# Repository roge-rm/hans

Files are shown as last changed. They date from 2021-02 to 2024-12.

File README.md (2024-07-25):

# hans
### Hans is a 5 button battery powered USB/MIDI footswitch<br>

Check Hans out on: [Youtube](https://www.youtube.com/watch?v=nbIn7SEke0U) | [Thingiverse](https://www.thingiverse.com/thing:4768840)

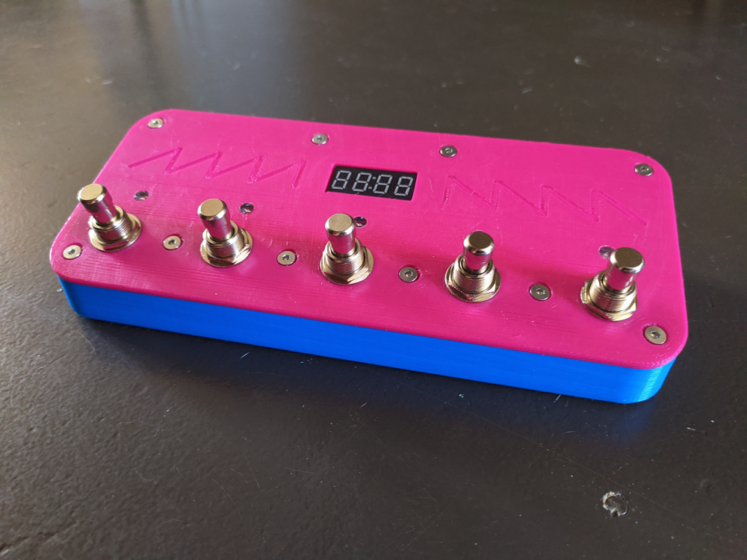
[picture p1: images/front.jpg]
<br>
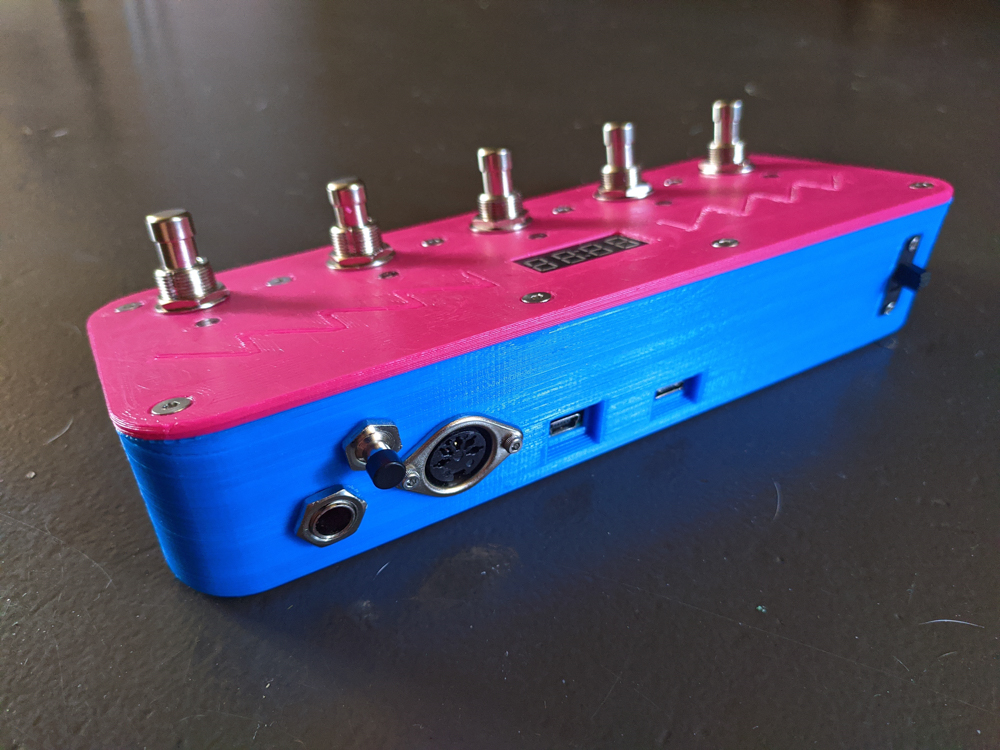
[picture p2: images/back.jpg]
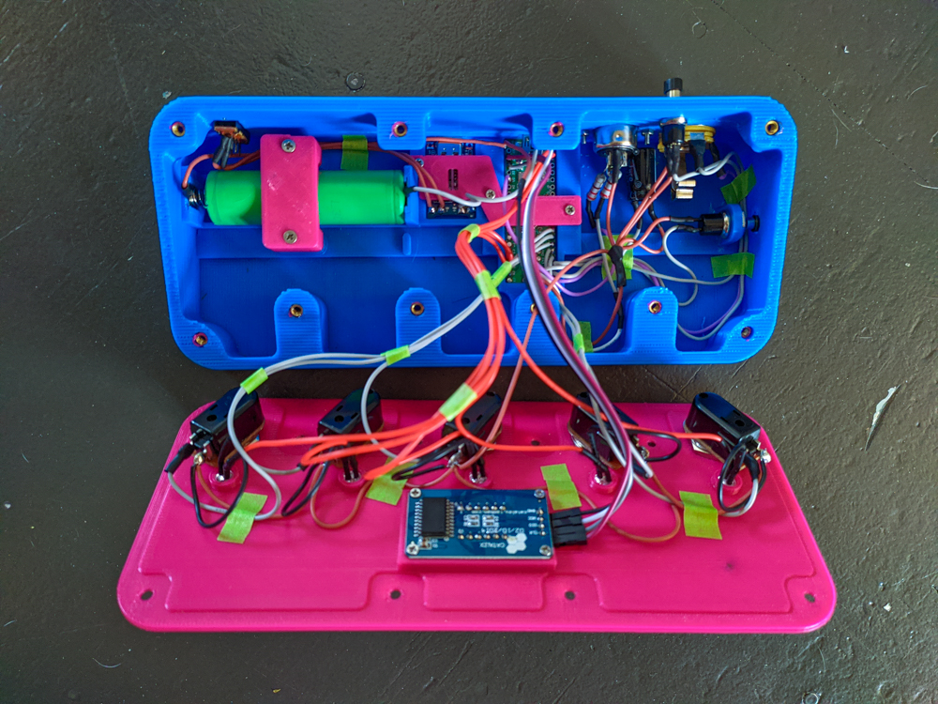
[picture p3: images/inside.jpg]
<br>

This is a continuation of a couple of previous projects of mine [[1]](https://github.com/hunked/eightbuttonMIDIfootswitch)[[2]](https://github.com/hunked/footie). 

My goal is to make a durable, 3D printed, battery powered, MIDI footswitch that outputs over USB and 5 pin MIDI. <br>
For cheap.<br>

Why did I name it Hans? No good reason at all.

### Hans has the following hardware/features:
- 5 momentary foot switches with status LEDs
- Expression pedal input (works in all button modes)
- Up to 5 virtual "banks" of buttons that can be switched between (3 enabled by default but can be changed in the edit menu)
- Full editing of all footswitch functions from the switch itself - you don't need to use your computer at all to change any settings. 
- Changes can be saved to EEPROM and will be loaded automatically on startup.
- USB-C charging with an 18650 on board for portable power
- USB (mini) and 5-pin MIDI cable connections for MIDI data
- [Teensy 2.0++](https://www.pjrc.com/store/teensypp.html) brains running at a blazing 16Mhz
- a 4 character screen

When Hans is turned on you can choose between four modes: 
- send MIDI note on/off messages (*alternative momentary mode can be activated to send note on for both press & release*)
- send MIDI control change (CC) messages
- send MIDI program change (PC) messages
- an edit mode to customize all features of the footswitch

The first three modes are self-explanatory. Both the note on/off and CC modes can be toggled between momentary and toggle operations (done by holding shift + pressing button 2), and each note can be switched between two momentary modes; one sends note on/note off on press/release and the other sends note on messages on both press and reelease.

The edit mode allows changing most of the settings on the device. You can change the midi notes sent (and the velocity sent with them), the control change numbers and values, and program change numbers. You can also edit the default mode (in case you want to start in CC or PC mode), the timeout before the default mode is selected, and various other settings like screen and LED brightness.

### How to use Hans:
- Turn Hans on.
- You will be presented with a mode selection screen. Press a button to choose a mode. <br>If no mode choice is made the default will be chosen after a timeout (5 seconds).
  * Button 1 - Note On/Off
  * Button 2 - Control Change
  * Button 3 - Program Change
  * Button 5 - Edit Mode
- If you selected modes 1 through 3:
  * Press the footswitch buttons to send the note/CC/PC message associated with that button.
  * Hold the shift button and press one of the front switches for additional functions:
    * Button 1/5 - Change button bank (-/+)
    * Button 2 - Switch between momentary/toggle modes
    * Button 3 - Return to mode select menu
    * Button 4 - Panic! Stop all playing notes
- If you selected edit mode:
  * Navigate through menus/submenus using the following buttons:
    * Button 1 - Go back to previous menu
    * Button 2 - Previous item (in menu) OR Reduce value by 1 (when editing)
    * Button 3 - Select item (in menu) or accept value (when editing)
    * Button 4 - Next item (in menu) or Increase value by 1 (when editing)
  * **Changes will not be saved to EEPROM (to be loaded on next startup) unless you select SAVE from the either the main menu or under the DATA submenu.** If you make a change you do not like you can either restart the unit, load the settings from EEPROM (under DATA submenu), or load the factory defaults (also under DATA submenu).

### Updating Hans:

Hans can be easily updated from a computer running Windows 7/8/10. 

1. Download the Teensy Loader app [from here](https://www.pjrc.com/teensy/loader_win10.html)
2. Download the [latest release](https://github.com/hunked/hans/releases) HEX file
3. Run the Teensy Loader and connect your Hans to your computer using a mini-USB cable
4. Open the hex file you downloaded in Teensy Loader and enable automatic mode in the loader
5. Press the programming button on your Hans (the one embedded in the right side) and the firmware will upload
6. Disconnect Hans when complete - you are ready!

### Replacing/Installing Battery:

You can install/remove/replace the battery in your Hans by following these steps:

1. Ensure the power to Hans is turned off, no cables are connected, etc.
2. Remove the ten hex screws on the face and set aside.
3. Carefully lift the back of the face of footswitch and flip it forward, making sure not to snag any wiring.
4. Remove the two phillips screws holding the battery clamp down.
5. Insert/remove/replace the battery as needed.
6. Reinstall the battery clamp with the two screws.
7. Carefully flip the face of the footswitch back onto the base, making sure not to snag any wiring.
8. Install the ten hex screws on the face in whatever order pleases you. I like to install from the centre outwards.

You may need a bit of gentle pressure when reinstalling the face to push any wiring down - however it should not be snagged anywhere and you should not have to force the face down onto the base. There should be enough room in the inner cavity to neatly fold any wiring into a place that does not cause any stress to the wiring or internal components.

### Pinout:<br>
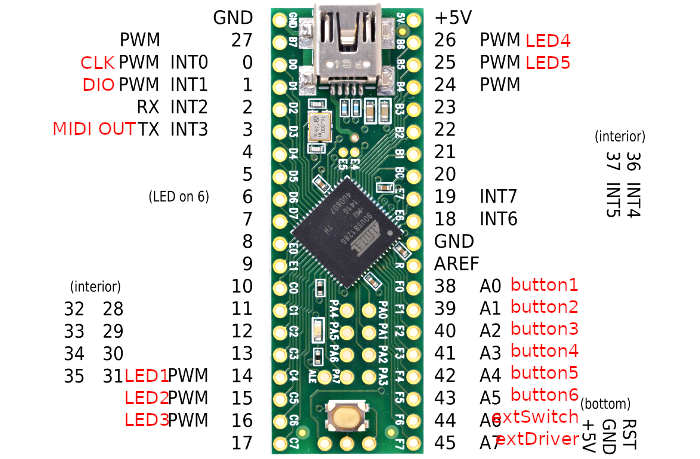
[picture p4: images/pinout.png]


### KiCad Schematic:<br>
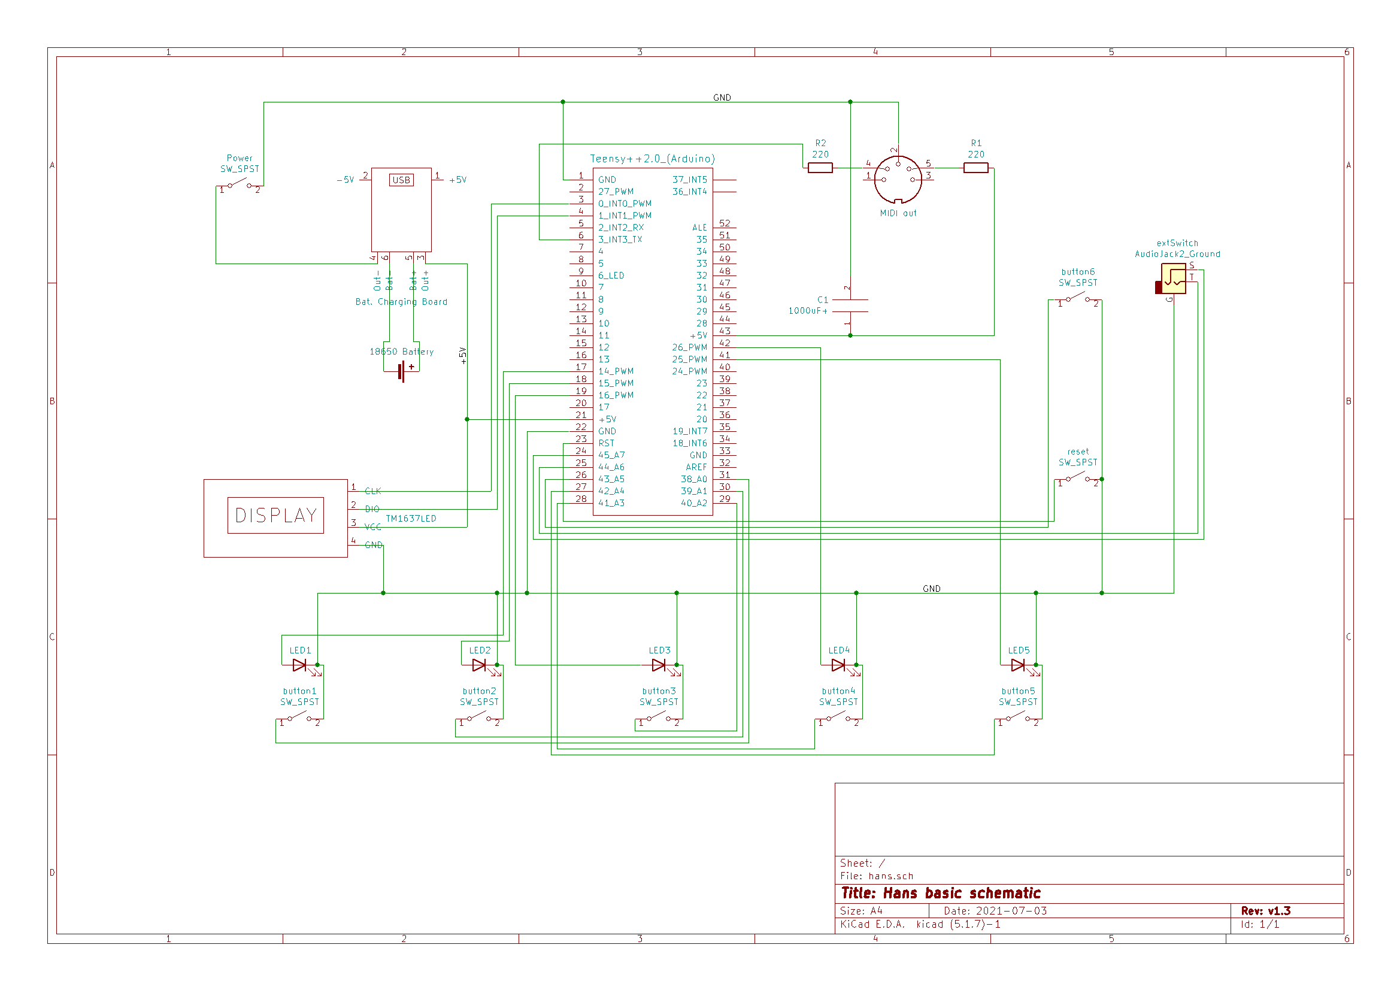
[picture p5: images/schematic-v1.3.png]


### Parts list:
| Name | Quantity |
|---|---|
| [Toggle Switch 2 Position 6 Pins](https://www.aliexpress.com/item/32800053774.html) | 1 |
| [SPST Momentary Soft Touch Push Button Stomp Foot Pedal Switch](https://www.aliexpress.com/item/32918205335.html) | 5 |
| [6.35mm Mono Female Jack With Switch Socket Panel Adapter](https://www.aliexpress.com/item/32614113278.html) | 1 |
| [5 Pin Panel Mount Female Jack DIN Adapter MIDI Connector](https://www.aliexpress.com/item/32972269819.html) | 1 |
| [7mm Momentary Push button Switch](https://www.aliexpress.com/item/32790920961.html) | 2 |
| [TM1637 4 Bits Digital LED Display Module](https://www.aliexpress.com/item/32387190376.html) | 1 |
| [Flat Top 5V 5mm Red LED Lamp w/integrated resistor](https://www.aliexpress.com/item/32904653006.html) | 5 |
| [Type-C 5V 1A 18650 Lithium Battery Charger Module](https://www.aliexpress.com/item/32670803042.html) | 1 |
| [Battery Spring and Plate Set](https://www.aliexpress.com/item/32881285245.html) | 1 |
| [Teensy 2.0++ USB AVR Development Board](https://www.pjrc.com/store/teensypp.html) or [clone](https://www.aliexpress.com/item/32975352827.html) | 1 |
| [1000uF+ 6.3V+ Capacitor](https://www.aliexpress.com/item/4000092084550.html) | 1 |
| [220 Ohm Resistor 1/4W](https://www.aliexpress.com/item/32952657927.html) | 2 |
| [M3 Thread Knurled Brass Threaded Heat Set](https://www.aliexpress.com/item/4001185849382.html) | 10 |
| [M3x10 Stainless Countersunk Hex Head Bolt](https://www.aliexpress.com/item/4000020967604.html) | 10 |
| [M2x6mm Stainless Countersunk Self-Tapping Screw](https://www.aliexpress.com/item/4001074924245.html) | 6 |
| [M2x10mm Stainless Hex Head Bolt](https://www.aliexpress.com/item/32810852732.html) | 2 |
| [M2 Stainless Nut](https://www.aliexpress.com/item/32977174437.html) | 2 |

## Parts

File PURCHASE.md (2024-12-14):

### Purchase a prebuilt Hans
I had a couple of prebuilt units for sale but they are gone.
Thanks!

### Currently for sale:
None for sale, thanks for looking!

### Sold:
**Serial:** 001<br>
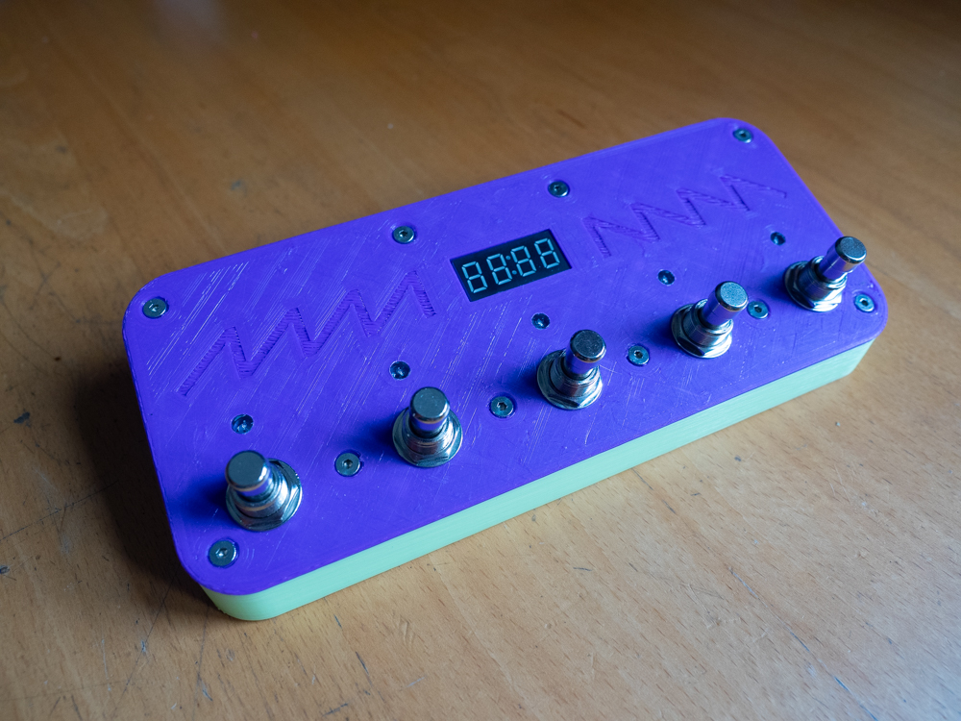
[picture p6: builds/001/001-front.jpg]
<br>
**Colours:** Light Green Base/Purple Top<br>
**Pictures:** [Rear](https://raw.githubusercontent.com/hunked/hans/main/builds/001/001-rear.jpg) [Top](https://raw.githubusercontent.com/hunked/hans/main/builds/001/001-top.jpg) [Bottom](https://raw.githubusercontent.com/hunked/hans/main/builds/001/001-bottom.jpg) [Inside](https://raw.githubusercontent.com/hunked/hans/main/builds/001/001-inside.jpg) 

**Serial:** 002<br>
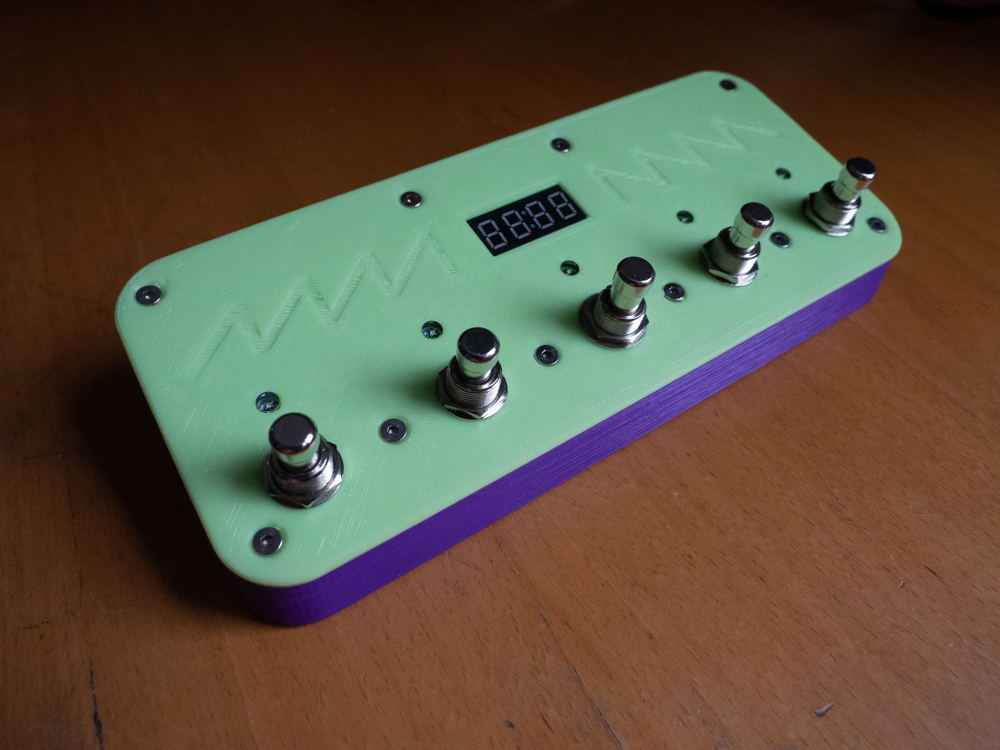
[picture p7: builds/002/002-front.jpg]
<br>
**Colours:** Purple Base/Light Green Top<br>
**Pictures:** [Rear](https://raw.githubusercontent.com/hunked/hans/main/builds/002/002-rear.jpg) [Top](https://raw.githubusercontent.com/hunked/hans/main/builds/002/002-top.jpg) [Bottom](https://raw.githubusercontent.com/hunked/hans/main/builds/002/002-bottom.jpg) [Inside](https://raw.githubusercontent.com/hunked/hans/main/builds/002/002-inside.jpg)

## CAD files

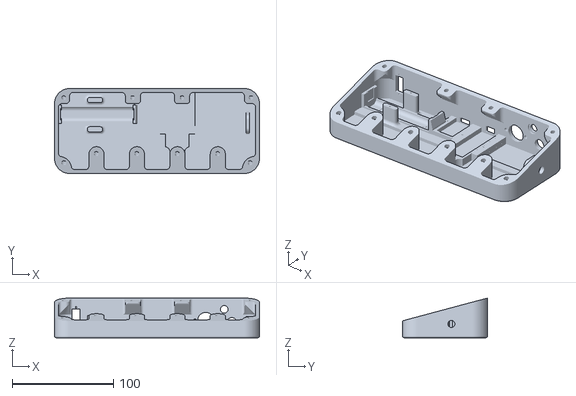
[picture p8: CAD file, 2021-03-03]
stl/v57-Main.stl
202.7 x 84.0 x 39.4

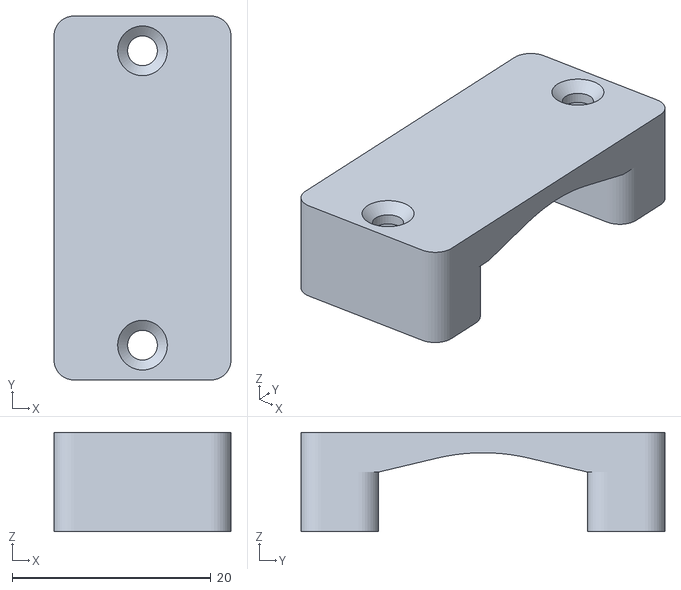
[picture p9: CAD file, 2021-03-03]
stl/v57-Battery Clamp.stl
17.8 x 36.6 x 10.0

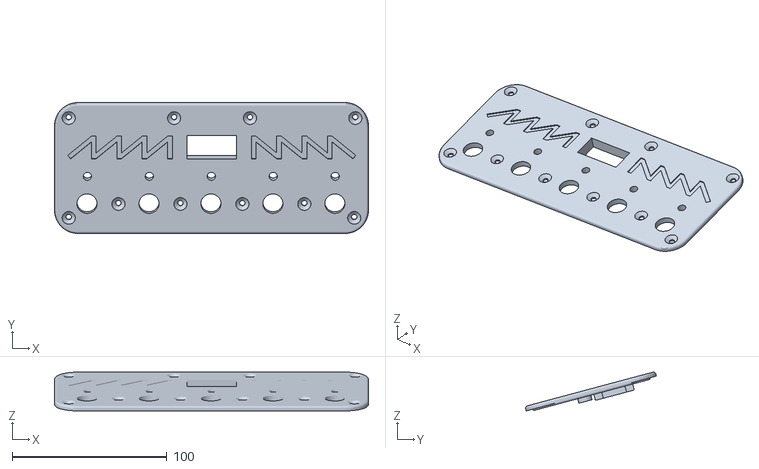
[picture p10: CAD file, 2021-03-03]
stl/v57-Top.stl
202.7 x 84.4 x 25.1

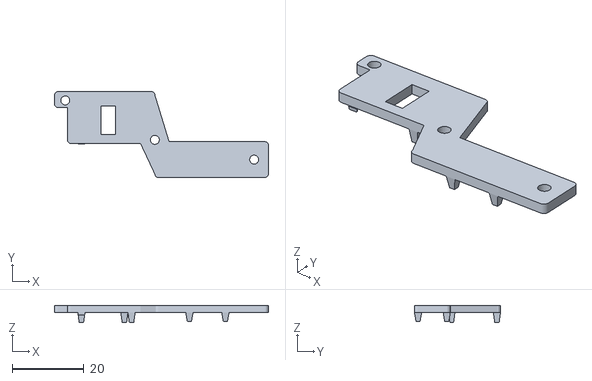
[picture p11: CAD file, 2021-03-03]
stl/v57-Board Clamp.stl
59.7 x 24.0 x 4.75

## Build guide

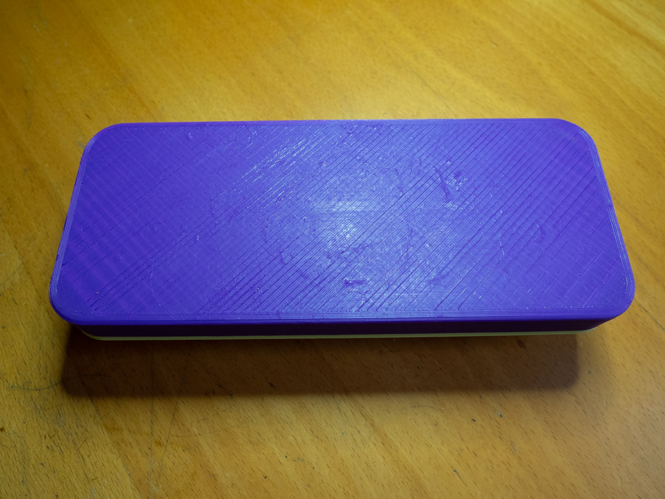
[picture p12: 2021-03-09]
builds/002/002-bottom.jpg

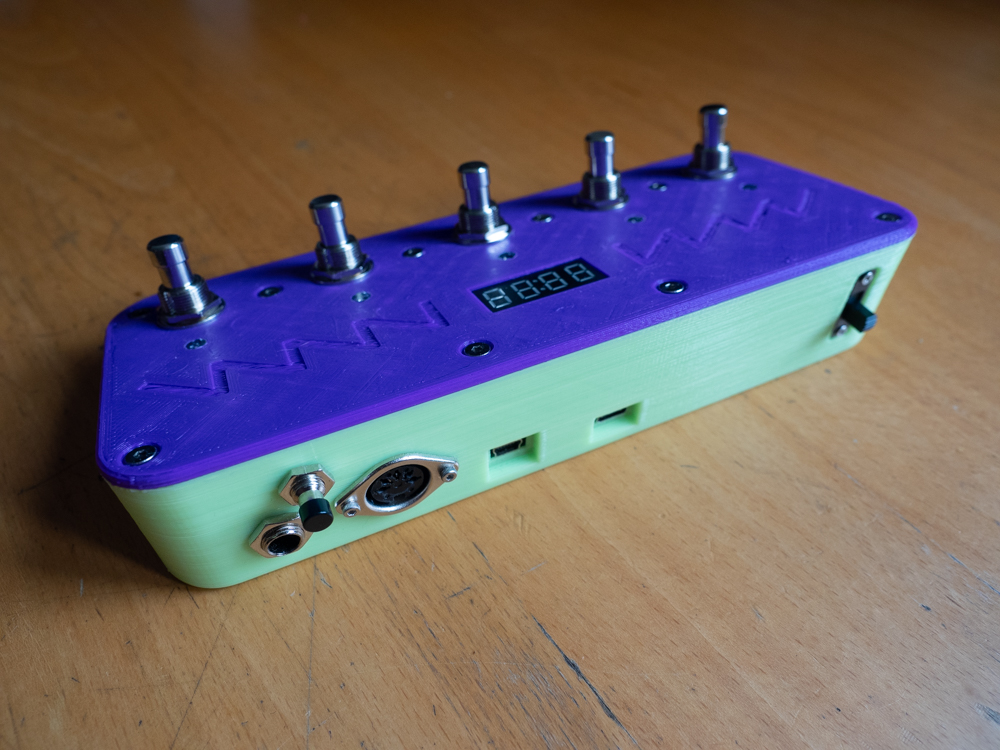
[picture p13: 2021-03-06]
builds/001/001-rear.jpg

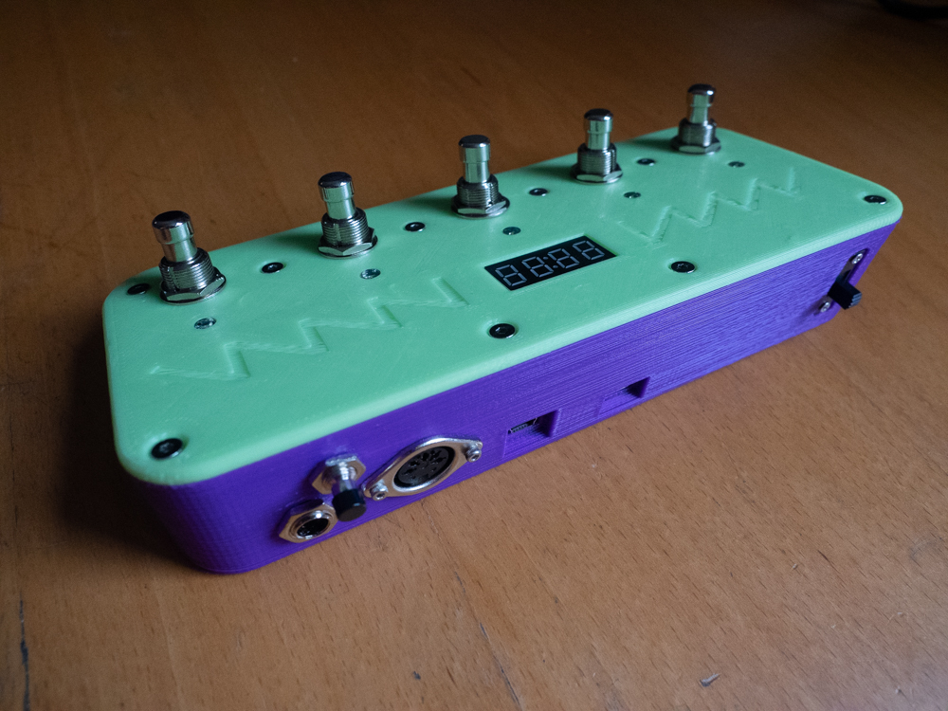
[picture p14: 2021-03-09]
builds/002/002-rear.jpg

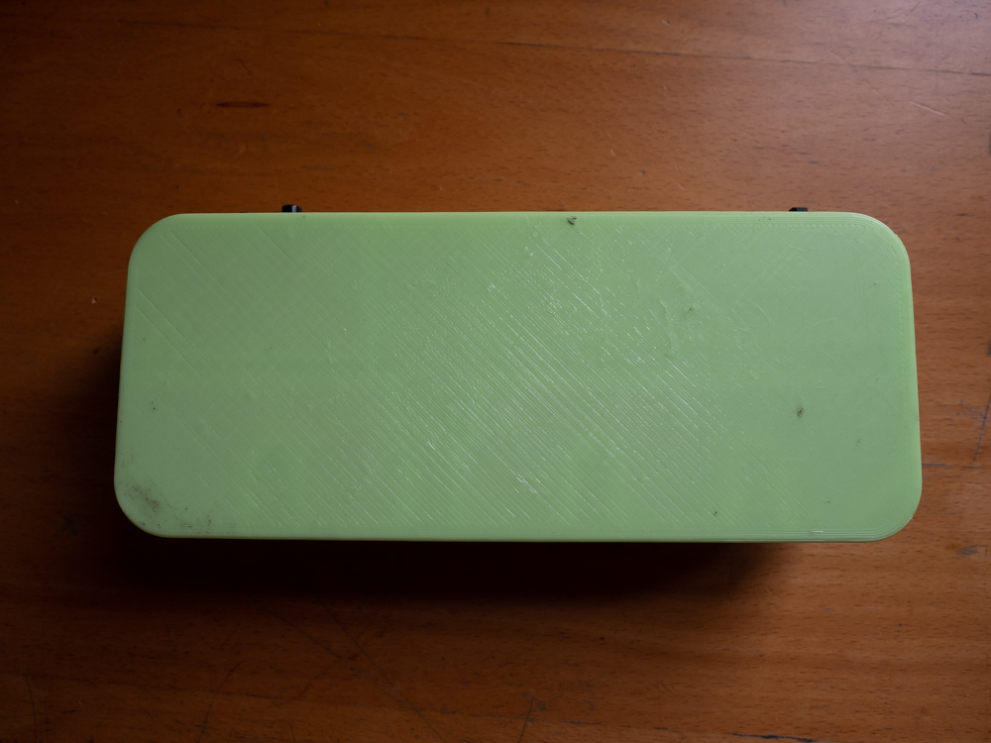
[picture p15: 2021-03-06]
builds/001/001-bottom.jpg

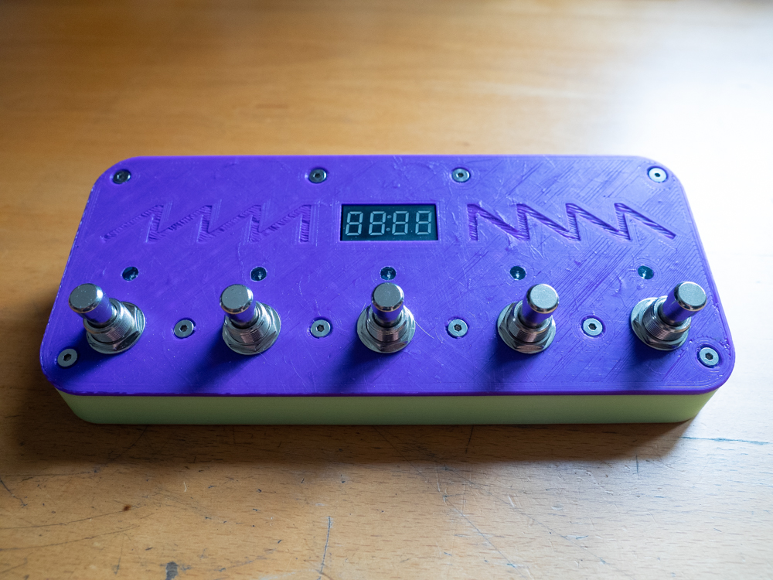
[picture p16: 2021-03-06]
builds/001/001-top.jpg

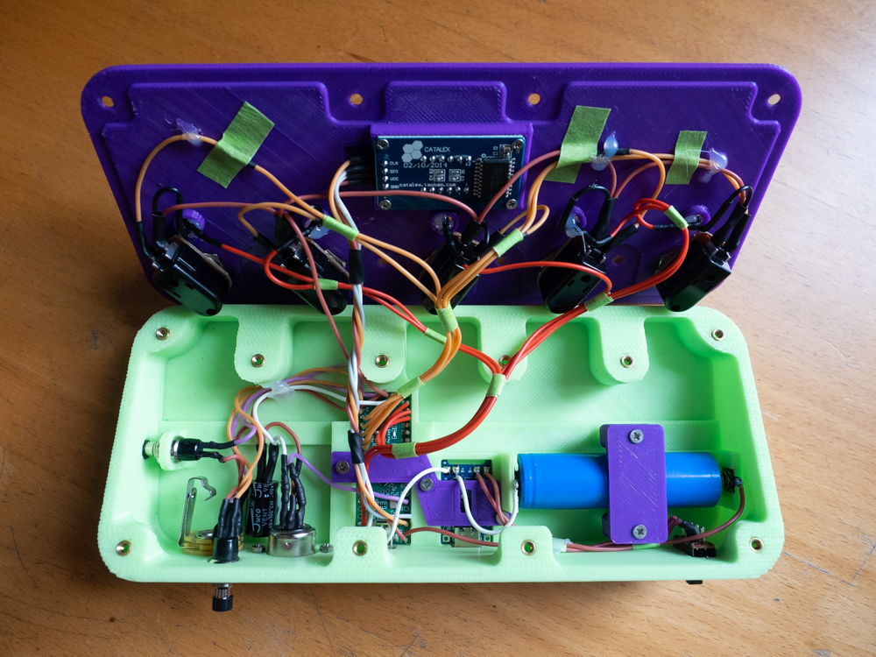
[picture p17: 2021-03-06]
builds/001/001-inside.jpg

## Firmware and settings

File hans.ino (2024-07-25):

/*
   5 buttons and an expression pedal walk in to a bar.
*/

#define buildRev "20240725"
bool intro;  // set by EEPROM - decide whether to show the name/buildrev intro text - set in eeprom

#include <Bounce2.h>
#include <MIDI.h>
#include <EEPROM.h>
#include <TM1637TinyDisplay.h>

// create MIDI instance for 5 pin MIDI output
MIDI_CREATE_INSTANCE(HardwareSerial, Serial1, MIDI);

// for buttons and external expression pedal (acts as an extra button)
const byte switchPin[6] = { 38, 39, 40, 41, 42, 43 };
const byte potPin = 44;
int potCC = 4;  // what CC the expression pedal should send
int potValue;   // store value of external pedal

// shift mode is enabled when rear button is pressed
bool shift = false;

// control whether button presses are momentary (false) or toggle (only applies to note and CC modes)
bool toggle;
bool toggleDefault;  // set by EEPROM

// LED settings
int ledBright;  // set by EEPROM - control LED brightness
const byte ledPin[5] = { 14, 15, 16, 26, 25 };
const int ledDelay = 125;  //How long to light LEDs up for visual confirmation

//Default channel for MIDI notes, CC, program change
int midiChan[3];  // set by EEPROM

// can select from up to 5 switchBanks of notes/velocities/etc - defaults to 3
int switchBank = 0;
int numBanks;  // set by EEPROM

// arrays are declared here but loaded from EEPROM/defaults in eepromREAD()
int switchNotes[5][5];       // note messages
int switchVels[5][5];        // note velocity
bool switchAltMoment[5][5];  // enable alternative momentary mode - this sends a note on message on button press and another note on message on button release
int switchCCs[5][5];         // CC numbers
int switchCCValOns[5][5];    // CC on value
int switchCCValOffs[5][5];   // CC off value
int switchPCs[5][5];         // PC numbers

bool ledStatus[5][5] = { { 0, 0, 0, 0, 0 }, { 0, 0, 0, 0, 0 }, { 0, 0, 0, 0, 0 }, { 0, 0, 0, 0, 0 }, { 0, 0, 0, 0, 0 } };

// switch states for runModes that require toggling
bool switchStates[5][5] = { { 0, 0, 0, 0, 0 }, { 0, 0, 0, 0, 0 }, { 0, 0, 0, 0, 0 }, { 0, 0, 0, 0, 0 }, { 0, 0, 0, 0, 0 } };

bool buttonStates[6] = { 0, 0, 0, 0, 0, 0 };  // track whether each button is held or not
unsigned long buttonPressTime[6];             // track how long button is pressed for
const int buttonRepeatDelay = 250;            // how long a button must be pressed for to count as a repeat (when editing)

// create Bounce objects for each button and switch.
Bounce button1 = Bounce();
Bounce button2 = Bounce();
Bounce button3 = Bounce();
Bounce button4 = Bounce();
Bounce button5 = Bounce();
Bounce button6 = Bounce();

// Track runMode (function of footswitch) as well as pick default option if no change is made before timeout. Default timeout is 6000ms.
// 0 = Startup screen (runMode select)
// 1 = MIDI Note
// 2 = MIDI CC
// 3 = Program Change
// 5 = Edit mode
int runMode = 0;
int runModeDefault = 1;  // set by EEPROM
int runmodeTime;
int runmodeDefaultTime;          // set by EEPROM - time in s to display runmode menu before selecting default
const int runmodeTimeLong = 30;  // time in s to display runmode when you return to it manually during operation
elapsedMillis timeOut;

// for settings menu navigation
int menuPos[4] = { 0, 0, 0, 0 };
int menuSelect = 0;
char menuListMain[7][5] = { "CHAN", "NOTE", "CC", "PC", "SET", "DATA", "SAVE" };
char menuListChan[3][5] = { "NOTE", "CC", "PC" };
char menuListNote[3][5] = { "NOTE", "VEL", "ALTM" };
char menuListCC[3][5] = { "CC", "V ON", "VOFF" };
char menuListSettings[9][5] = { "DRUN", "TIME", "BANK", "TOGG", "EXSW", "LEDB", "SCRB", "INFO", "IDLE" };
char menuListData[3][5] = { "LOAD", "SAVE", "DEF" };
char idleText[6][5] = { "hans", " is ", " me", "hans", " is ", " on" };

const int wipeTime = 1000;  // max time in ms to display anything on the screen
int idleTimeOut;            // set by EEPROM - time in seconds to wait before showing a keepalive notification
int idleCounter = 0;        // used to run through idle messages in order
elapsedMillis screenWipe;
elapsedMillis idleTime;

// initialize display
const int clkPin = 0;
const int dioPin = 1;
int screenBright;       // set by EEPROM - control how bright the screen is from 0-7
int scrollDelay = 100;  // speed at which text scrolls on the screen
TM1637TinyDisplay display(clkPin, dioPin);

void setup() {
  // button setup
  button1.attach(switchPin[0], INPUT_PULLUP);
  button2.attach(switchPin[1], INPUT_PULLUP);
  button3.attach(switchPin[2], INPUT_PULLUP);
  button4.attach(switchPin[3], INPUT_PULLUP);
  button5.attach(switchPin[4], INPUT_PULLUP);
  button6.attach(switchPin[5], INPUT_PULLUP);

  // button debounce interval in ms
  button1.interval(5);
  button2.interval(5);
  button3.interval(5);
  button4.interval(5);
  button5.interval(5);
  button6.interval(5);

  eepromLoad();                      // load values from EEPROM - or from default set it nothing saved to EEPROMN
  runmodeTime = runmodeDefaultTime;  // set initial runmode timeout to default timeout
  toggle = toggleDefault;

  // display setup and greeting
  display.setBrightness(screenBright);
  display.setScrolldelay(scrollDelay);
  if (intro) {
    display.showString("hans");
    delay(750);
    display.showString(buildRev);
    delay(250);
  }
  display.clear();

  // initialize MIDI
  MIDI.begin();

  // configure switch pins as for input mode with pullup resistors
  pinMode(switchPin[0], INPUT_PULLUP);
  pinMode(switchPin[1], INPUT_PULLUP);
  pinMode(switchPin[2], INPUT_PULLUP);
  pinMode(switchPin[3], INPUT_PULLUP);
  pinMode(switchPin[4], INPUT_PULLUP);
  pinMode(switchPin[5], INPUT_PULLUP);

  // initialize built-in LED as an output.
  pinMode(ledPin[0], OUTPUT);
  pinMode(ledPin[1], OUTPUT);
  pinMode(ledPin[2], OUTPUT);
  pinMode(ledPin[3], OUTPUT);
  pinMode(ledPin[4], OUTPUT);

  updateButtons();  // pull initial button status to prevent phantom MIDI messages from being sent once the loop starts

  display.clear();
  timeOut = 0;

  potValue = 0;
}

void loop() {
  updatePot();      // update expression pedal
  updateButtons();  // poll for button presses.

  switch (runMode) {
    case 0:
      runModeSelectMode();
      idleTime = 0;
      break;
    case 1:
      runModeNote();
      break;
    case 2:
      runModeCC();
      break;
    case 3:
      runModePC();
      break;
    case 5:
      runModeSettings();
      idleTime = 0;
      break;
  }

  while (usbMIDI.read())  // ignore incoming MIDI
  {
  }

  if (button6.changed()) {
    if (button6.rose()) {
      shift = false;
    } else if (button6.fell()) {
      shift = true;
      display.showString("Shft");
      screenWipe = 0;
    }
  }

  // wipe the screen every wipeTime ms
  if (screenWipe >= wipeTime) {
    display.clear();
    screenWipe = 0;
  }

  // show a lil somethin on the screen every idleTimeOut
  // this is because I always forget to turn Hans off
  if (idleTimeOut > 0) {
    if (idleTime >= (idleTimeOut * 1000)) {
      display.showString(idleText[idleCounter]);
      if (idleCounter < 6) idleCounter++;
      else idleCounter = 0;
      idleTime = 0;
      screenWipe = 0;
    }
  }

  updateLEDs();  // update LED status
}

void updatePot() {
  int newpotValue;
  newpotValue = (analogRead(potPin) / 8);
  if (newpotValue < 3) newpotValue = 0;
  if (newpotValue > 125) newpotValue = 127;

  if (newpotValue != potValue) {
    usbMIDI.sendControlChange(potCC, newpotValue, midiChan[2]);
    MIDI.sendControlChange(potCC, newpotValue, midiChan[2]);
    //Serial.print("external input is: ");
    //Serial.println(newpotValue);
    display.showNumber(newpotValue);
    potValue = newpotValue;
  }
}

void updateButtons() {
  if (button1.update()) {
    buttonStates[0] = !button1.read();
    idleTime = 0;
    idleCounter = 0;
  }
  if (button2.update()) {
    buttonStates[1] = !button2.read();
    idleTime = 0;
    idleCounter = 0;
  }
  if (button3.update()) {
    buttonStates[2] = !button3.read();
    idleTime = 0;
    idleCounter = 0;
  }
  if (button4.update()) {
    buttonStates[3] = !button4.read();
    idleTime = 0;
    idleCounter = 0;
  }
  if (button5.update()) {
    buttonStates[4] = !button5.read();
    idleTime = 0;
    idleCounter = 0;
  }
  if (button6.update()) {
    buttonStates[5] = !button6.read();
    idleTime = 0;
    idleCounter = 0;
  }
}

void runModeSelectMode() {  // give choice between running modes, choose default mode after timeout if no option selected
  display.showString("Mode");

  ledStatus[switchBank][0] = 1;
  ledStatus[switchBank][1] = 1;
  ledStatus[switchBank][2] = 1;
  ledStatus[switchBank][4] = 1;

  if (button1.rose()) {
    resetLEDs();
    updateLEDs();
    runMode = 1;
    displayText(runMode - 1, 3);
  } else if (button2.rose()) {
    resetLEDs();
    updateLEDs();
    runMode = 2;
    displayText(runMode - 1, 3);
  } else if (button3.rose()) {
    resetLEDs();
    updateLEDs();
    runMode = 3;
    displayText(runMode - 1, 3);
  } else if (button5.rose()) {
    resetLEDs();
    updateLEDs();
    runMode = 5;
    displayText(runMode - 1, 3);
  }
  screenWipe = 0;

  if (timeOut >= (runmodeTime * 1000)) {
    resetLEDs();
    updateLEDs();
    runMode = runModeDefault;
    displayText(runMode - 1, 3);
    timeOut = 0;
  }
}

void runModeNote() {
  if (button1.changed() || button2.changed() || button3.changed() || button4.changed() || button5.changed()) {
    if (!shift) {     // shift mode disabled
      if (!toggle) {  // toggle mode disabled (aka momentary mode)
        if (button1.fell()) {
          display.showNumber(switchNotes[switchBank][0]);
          ledStatus[switchBank][0] = 1;
          usbMIDI.sendNoteOn(switchNotes[switchBank][0], switchVels[switchBank][0], midiChan[0]);
          MIDI.sendNoteOn(switchNotes[switchBank][0], switchVels[switchBank][0], midiChan[0]);
        } else if (button1.rose()) {
          display.showNumber(switchNotes[switchBank][0]);
          if (!switchAltMoment[switchBank][0]) {  // normal operation - alt momentary mode disabled
            usbMIDI.sendNoteOff(switchNotes[switchBank][0], 0, midiChan[0]);
            MIDI.sendNoteOff(switchNotes[switchBank][0], 0, midiChan[0]);
          } else if (switchAltMoment[switchBank][0]) {  // alt momentary mode enabled
            usbMIDI.sendNoteOn(switchNotes[switchBank][0], switchVels[switchBank][0], midiChan[0]);
            MIDI.sendNoteOn(switchNotes[switchBank][0], switchVels[switchBank][0], midiChan[0]);
          }
          ledStatus[switchBank][0] = 0;
        }

        if (button2.fell()) {
          display.showNumber(switchNotes[switchBank][1]);
          ledStatus[switchBank][1] = 1;
          usbMIDI.sendNoteOn(switchNotes[switchBank][1], switchVels[switchBank][1], midiChan[0]);
          MIDI.sendNoteOn(switchNotes[switchBank][1], switchVels[switchBank][1], midiChan[0]);
        } else if (button2.rose()) {
          display.showNumber(switchNotes[switchBank][1]);
          if (!switchAltMoment[switchBank][1]) {
            usbMIDI.sendNoteOff(switchNotes[switchBank][1], 0, midiChan[0]);
            MIDI.sendNoteOff(switchNotes[switchBank][1], 0, midiChan[0]);
          } else if (switchAltMoment[switchBank][1]) {
            usbMIDI.sendNoteOn(switchNotes[switchBank][1], switchVels[switchBank][1], midiChan[0]);
            MIDI.sendNoteOn(switchNotes[switchBank][1], switchVels[switchBank][1], midiChan[0]);
          }
          ledStatus[switchBank][1] = 0;
        }

        if (button3.fell()) {
          display.showNumber(switchNotes[switchBank][2]);
          ledStatus[switchBank][2] = 1;
          usbMIDI.sendNoteOn(switchNotes[switchBank][2], switchVels[switchBank][2], midiChan[0]);
          MIDI.sendNoteOn(switchNotes[switchBank][2], switchVels[switchBank][2], midiChan[0]);
        } else if (button3.rose()) {
          display.showNumber(switchNotes[switchBank][2]);
          if (!switchAltMoment[switchBank][2]) {
            usbMIDI.sendNoteOff(switchNotes[switchBank][2], 0, midiChan[0]);
            MIDI.sendNoteOff(switchNotes[switchBank][2], 0, midiChan[0]);
          } else if (switchAltMoment[switchBank][2]) {
            usbMIDI.sendNoteOn(switchNotes[switchBank][2], switchVels[switchBank][2], midiChan[0]);
            MIDI.sendNoteOn(switchNotes[switchBank][2], switchVels[switchBank][2], midiChan[0]);
          }
          ledStatus[switchBank][2] = 0;
        }

        if (button4.fell()) {
          display.showNumber(switchNotes[switchBank][3]);
          ledStatus[switchBank][3] = 1;
          usbMIDI.sendNoteOn(switchNotes[switchBank][3], switchVels[switchBank][3], midiChan[0]);
          MIDI.sendNoteOn(switchNotes[switchBank][3], switchVels[switchBank][3], midiChan[0]);
        } else if (button4.rose()) {
          display.showNumber(switchNotes[switchBank][3]);
          if (!switchAltMoment[switchBank][3]) {
            usbMIDI.sendNoteOff(switchNotes[switchBank][3], 0, midiChan[0]);
            MIDI.sendNoteOff(switchNotes[switchBank][3], 0, midiChan[0]);
          } else if (switchAltMoment[switchBank][3]) {
            usbMIDI.sendNoteOn(switchNotes[switchBank][3], switchVels[switchBank][3], midiChan[0]);
            MIDI.sendNoteOn(switchNotes[switchBank][3], switchVels[switchBank][3], midiChan[0]);
          }
          ledStatus[switchBank][3] = 0;
        }

        if (button5.fell()) {
          display.showNumber(switchNotes[switchBank][4]);
          ledStatus[switchBank][4] = 1;
          usbMIDI.sendNoteOn(switchNotes[switchBank][4], switchVels[switchBank][4], midiChan[0]);
          MIDI.sendNoteOn(switchNotes[switchBank][4], switchVels[switchBank][4], midiChan[0]);
        } else if (button5.rose()) {
          display.showNumber(switchNotes[switchBank][4]);
          if (!switchAltMoment[switchBank][4]) {
            usbMIDI.sendNoteOff(switchNotes[switchBank][4], 0, midiChan[0]);
            MIDI.sendNoteOff(switchNotes[switchBank][4], 0, midiChan[0]);
          } else if (switchAltMoment[switchBank][4]) {
            usbMIDI.sendNoteOn(switchNotes[switchBank][4], switchVels[switchBank][4], midiChan[0]);
            MIDI.sendNoteOn(switchNotes[switchBank][4], switchVels[switchBank][4], midiChan[0]);
          }
          ledStatus[switchBank][4] = 0;
        }
      } else if (toggle) {
        if (button1.fell()) {
          display.showNumber(switchNotes[switchBank][0]);
          if (switchStates[switchBank][0] == 0) {
            switchStates[switchBank][0] = 1;
            usbMIDI.sendNoteOn(switchNotes[switchBank][0], switchVels[switchBank][0], midiChan[0]);
            MIDI.sendNoteOn(switchNotes[switchBank][0], switchVels[switchBank][0], midiChan[0]);
            ledStatus[switchBank][0] = 1;
          } else {
            switchStates[switchBank][0] = 0;
            usbMIDI.sendNoteOff(switchNotes[switchBank][0], 0, midiChan[0]);
            MIDI.sendNoteOff(switchNotes[switchBank][0], 0, midiChan[0]);
            ledStatus[switchBank][0] = 0;
          }
        }

        if (button2.fell()) {
          display.showNumber(switchNotes[switchBank][1]);
          if (switchStates[switchBank][1] == 0) {
            switchStates[switchBank][1] = 1;
            usbMIDI.sendNoteOn(switchNotes[switchBank][1], switchVels[switchBank][1], midiChan[0]);
            MIDI.sendNoteOn(switchNotes[switchBank][1], switchVels[switchBank][1], midiChan[0]);
            ledStatus[switchBank][1] = 1;
          } else {
            switchStates[switchBank][1] = 0;
            usbMIDI.sendNoteOff(switchNotes[switchBank][1], 0, midiChan[0]);
            MIDI.sendNoteOff(switchNotes[switchBank][1], 0, midiChan[0]);
            ledStatus[switchBank][1] = 0;
          }
        }

        if (button3.fell()) {
          display.showNumber(switchNotes[switchBank][2]);
          if (switchStates[switchBank][2] == 0) {
            switchStates[switchBank][2] = 1;
            usbMIDI.sendNoteOn(switchNotes[switchBank][2], switchVels[switchBank][2], midiChan[0]);
            MIDI.sendNoteOn(switchNotes[switchBank][2], switchVels[switchBank][2], midiChan[0]);
            ledStatus[switchBank][2] = 1;
          } else {
            switchStates[switchBank][2] = 0;
            usbMIDI.sendNoteOff(switchNotes[switchBank][2], 0, midiChan[0]);
            MIDI.sendNoteOff(switchNotes[switchBank][2], 0, midiChan[0]);
            ledStatus[switchBank][2] = 0;
          }
        }

        if (button4.fell()) {
          display.showNumber(switchNotes[switchBank][3]);
          if (switchStates[switchBank][3] == 0) {
            switchStates[switchBank][3] = 1;
            usbMIDI.sendNoteOn(switchNotes[switchBank][3], switchVels[switchBank][3], midiChan[0]);
            MIDI.sendNoteOn(switchNotes[switchBank][3], switchVels[switchBank][3], midiChan[0]);
            ledStatus[switchBank][3] = 1;
          } else {
            switchStates[switchBank][3] = 0;
            usbMIDI.sendNoteOff(switchNotes[switchBank][3], 0, midiChan[0]);
            MIDI.sendNoteOff(switchNotes[switchBank][3], 0, midiChan[0]);
            ledStatus[switchBank][3] = 0;
          }
        }

        if (button5.fell()) {
          display.showNumber(switchNotes[switchBank][4]);
          if (switchStates[switchBank][4] == 0) {
            switchStates[switchBank][4] = 1;
            usbMIDI.sendNoteOn(switchNotes[switchBank][4], switchVels[switchBank][4], midiChan[0]);
            MIDI.sendNoteOn(switchNotes[switchBank][4], switchVels[switchBank][4], midiChan[0]);
            ledStatus[switchBank][4] = 1;
          } else {
            switchStates[switchBank][4] = 0;
            usbMIDI.sendNoteOff(switchNotes[switchBank][4], 0, midiChan[0]);
            MIDI.sendNoteOff(switchNotes[switchBank][4], 0, midiChan[0]);
            ledStatus[switchBank][4] = 0;
          }
        }
      }
    } else if (shift) {
      shiftMode();
    }
  }
}
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

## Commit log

2021-02-20 v47 files
    v47 moves the reset button to the right side with a special internal mount (as it is not needed except when updating firmware)
    [v47-Battery Clamp.stl, v47-Board Clamp.stl, v47-Main.stl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]
2021-02-20 simple version made with OneButton library
    mostly proof of concept at this point - the code sends midi notes on button "click" and allows for changing button banks with long-press of buttons 1 and 5
    likely will not keep this library as I prefer code that allows for press/release of button (important for sending CC on/off messages)
2021-02-20 Add files via upload
    initial upload - supports changing virtual banks of switches while using external switch
    I don't like the performance I get when using click/release detection along with long press/double click actions
    this may change in the future
2021-02-22 Add files via upload
    new housing revision with reset button on side, shift button on back (does same thing as external switch does)
2021-02-22 Add files via upload
    biggest changes are now there are two 7mm momentary buttons - one embedded in the side for reset (not accessible easily) and one on the back as a shift button in case there is no external switch attached
    [v53-Battery Clamp.stl, v53-Board Clamp.stl, v53-Main.stl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]
2021-02-24 Update hans.ino
    changed LEDs to analogWrite, added a variable for LED brightness (will be adjustable from the edit menu in the future)
    default LED brightness set to 5
2021-02-27 Update hans.ino
    added EEPROM functions:
    load from EEPROM (done on startup automatically)
    save to EEPROM (must be done manually to limit unnecessary writes)
    load defaults
    now notes, CC, PC, channels, various defaults can be edited directly on the device and saved for later
2021-03-04 Update hans.ino
    editing values by pressing a button many times over is not fun so I added a repeat button function
    when you hold the button longer than x time (currently 250ms) the value will automatically increase/decrease every x time
    also did some code cleaning as there was a lot of copy/paste/change the first time around.. expect more of this as I am further embarassed by what I've done
2021-03-05 Update README.md
    wrong link for power switch
2021-03-05 Update hans.ino
    bug when pressing button 3 while editing PC values (wouldn't accept and return to previous menu)
    [hans.ino]
2021-03-05 Update hans.ino
    fix one bug forget one bug you know how it is
    [hans.ino]
2021-03-07 Update hans.ino
    added an alternative momentary switch to each note/button grouping
    enabling this will change the momentary behavour from send note on/note off on press/release to note on/note on on press/release
    this will allow holding a button (eg loop) for the Synthstrom Deluge for as long as you want to loop and then simply releasing it when done
    all credit goes to redditor neilbaldwn for this suggestion
2021-03-16 Update README.md
    added instructions for updating and battery replacement - will add some pictures for both shortly
2021-07-03 added kicad schematic
2021-07-03 added a schematic
    just a little thing I quickly drew up in KiCad
2021-07-03 updated cap location
    moved to right side of design to more accurately represent how I assembled the unit in real life
2024-07-25 change external button input to expression pedal input
    it was always my plan to add expression pedal input and now I have done it - this required replacing the external switch TS jackwith a TRS jack and moving code around to match
